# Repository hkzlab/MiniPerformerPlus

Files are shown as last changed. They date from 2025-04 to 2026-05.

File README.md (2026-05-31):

# MiniPerformer+

## DISCLAIMER

Any use of this project is **under your own responsibility**.
You will be responsible of checking the correct construction and functionality of your board.
By using this project You will agree that I cannot be held responsible if it will destroy any of your devices, damage your computer, burn down your house or whatever.

## Introduction

This board is a remix of the [Micromac Performer](https://github.com/TheRealBolle/Performer-SE-PL-CL) reversed by Bolle,
resized for installation on the Macintosh Plus clone I am using.

Ideally, it should be usable on original Mac Pluses too, try and let me know!

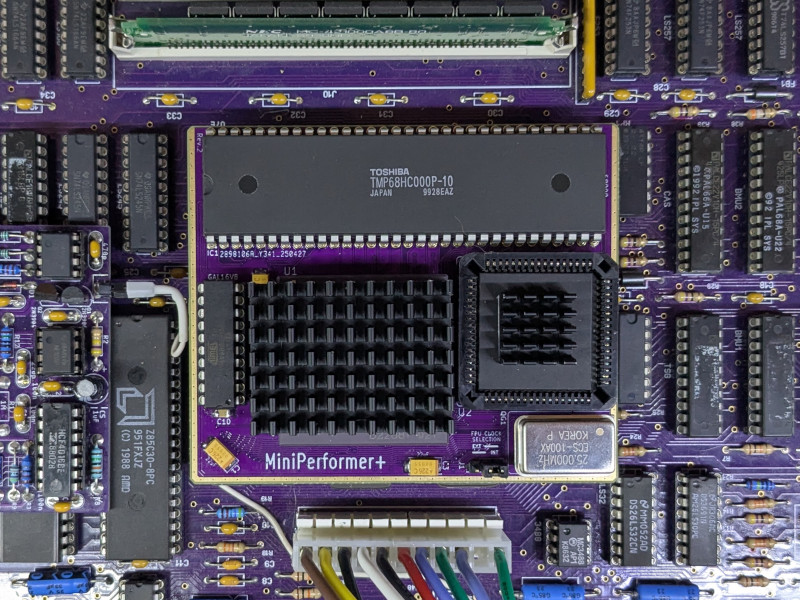
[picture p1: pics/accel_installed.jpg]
Rev. 2 board installed in a Mac Plus clone motherboard


### Caveat Emptor

The original Performer had a clip mounted on the underside that allowed it to snap on the motherboard's 68000 without desoldering.
Those clips are now hard to come by, so this accelerator is meant to be installed in place of the 68000, which has to be desoldered and socketed.

### Ordering the boards

You can order the board for this project at [PCBWay](https://www.pcbway.com/project/shareproject/MiniPerformer_d2c49c46.html) and support me or download 
the gerbers and have them printed wherever you like!!!

## Features

- Relatively easy to build, with socketed PLCC ICs
- ~16Mhz 68030 + optional 68882 with choice of clock source: 16Mhz internal or external oscillator

## Hardware

The board was designed with [KiCad](https://kicad.org/) EDA.

### Bill of Materials

| Component | Qty | Type / Value | Notes |
| --- | --- | --- | --- |
| R1 - R18 |  18 | 4.7k resistors, 1206 | |
| C4 - C14 |  11 | 100nF/16V ceramic cap, 1206 | |
| C1 - C3 |  3  | 22uF/16V or 25V tantalum capacitor, 6032 | |
| 68000 socket |  64 | Female machined pins, >=9.7mm length | You can source these on AliExpress, here is an [example](https://it.aliexpress.com/item/33019740866.html). |
| QG1 |  1  | DIP8 or DIP14 oscillator | Depending on the 68882, I had luck with frequencies ranging between 25 and 50Mhz |
| U1 |  1  | 68030, PGA-128 package | Avoid soldering the CPU to the board, use a socket!!! |
| U2 |  1  | 68882 FPU, optional, PLCC-68 package, requires socket | The FPU is optional, to install it, a PLCC-68 THT socket is required |
| U3 - U6 |  4  | PLCC-20 PLDs, 16V8 compatbile, an SMD PLCC socket is required  | I tested both GAL16V8D and AMD PALCE16V8 PLDs for this |
| U7 |  1  | DIP-20 PLD, 16V8 compatible | Avoid GAL16V8D, tested ATF16V8 and PALCE16V8 without issues |
| J3 |  1  | 3 pin 2.54mm header strip | Used to switch between internal and external clock source for FPU |

### Assembly

Start with the smallest SMD components: ceramic caps and resistors, on both sides of the board.
I usually do the 3 tantalum caps right after, then flip the board and install the 4 PLCC-20 sockets.

For the sockets, my usual approach is to snip away the bottom, apply copious flux on the PCB, align the sockets and then
apply solder, no need for hot air here. You do you though.

The nastiest part is installing the round pins in the 68000 footprint. Insert the pins from the topside of the board, then use a large flat blade screwdriver,
pushing the pins through the hole wiggling the pin completely in. Try not to hurt your fingers (like I did...) in the process.

The installed pins should look like this. Mind you, you will need pins >=9.7mm in length!

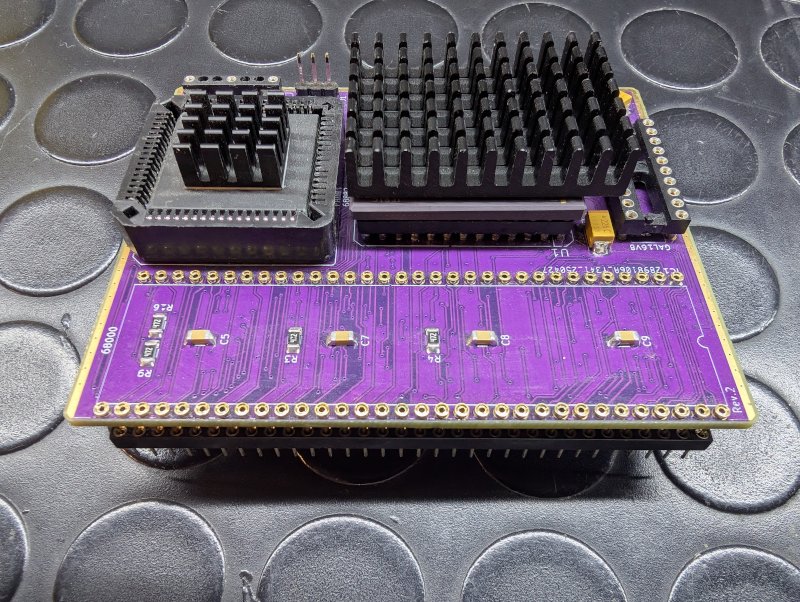
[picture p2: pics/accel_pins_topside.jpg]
Rev. 2 topside view


Once the rows are installed, I usually install a temporary socket on the pins to keep them in line, apply flux on the pcb, then solder every pin on the underside.
Try not to short them.

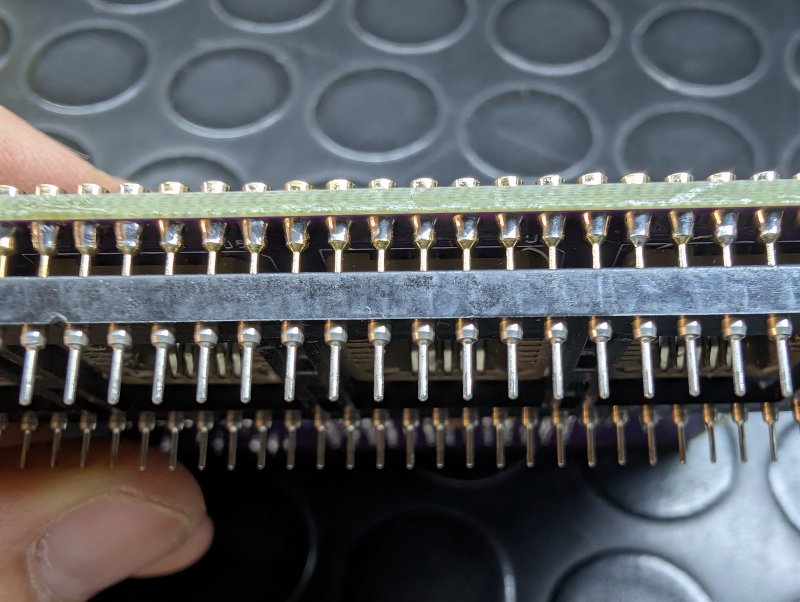
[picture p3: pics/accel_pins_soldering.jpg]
Rev. 2 sideways pins view


You can keep the through hole sockets and the 3 pin header last.

Once the all pins have been soldered, you can **VERY CAREFULLY** remove the holding socket. If you choose long enough pins, the accelerator will have enough clearance
at the bottom to install in the 68000 socket on the motherboard.

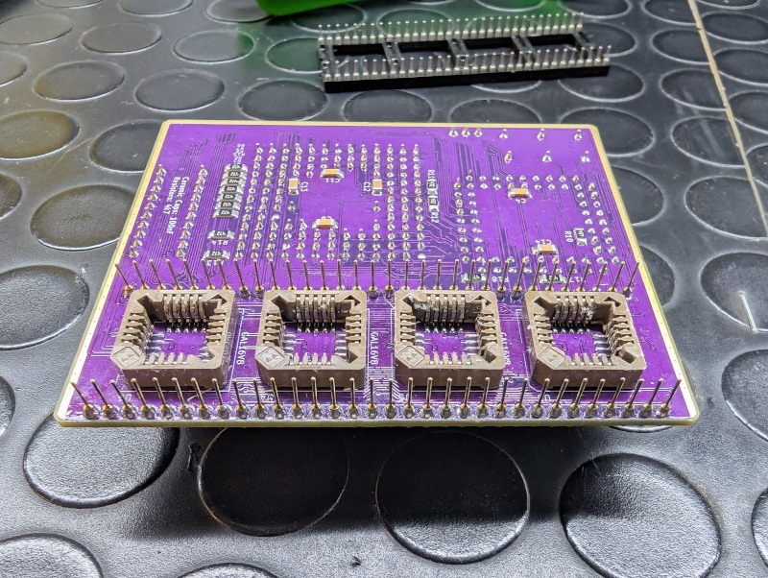
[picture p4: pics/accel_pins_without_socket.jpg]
Rev. 2 bottomside without socket


The PLDs must be programmed, the JED files can be found in [Bolle's repository](https://github.com/TheRealBolle/Performer-SE-PL-CL).

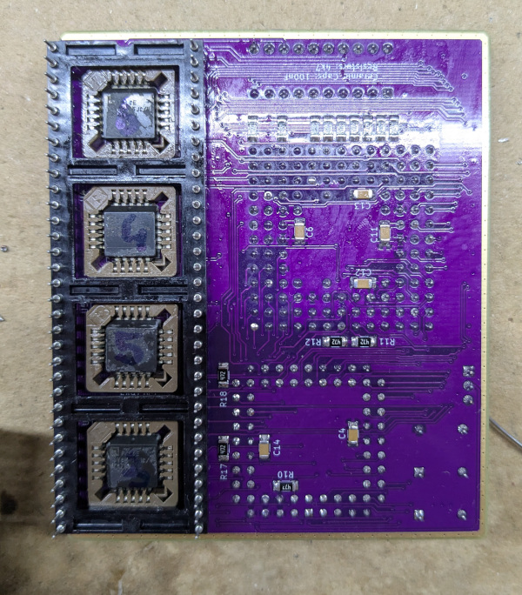
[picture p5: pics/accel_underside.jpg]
Rev. 2 board underside


### How to disable the accelerator

Turn on the Macintosh Plus then, after the chime sound, hold the interrupt button, and push reset after that. After another chime sound plays, release the interrupt button.

The accelerator will be disabled until the next boot.

### Known Issues

- While used without this board, my clone Mac Plus had no issues in using a WDC 65C22 and fast OTP ROMs. With the accelerator installed, it gets a bit finicky on the parts and sometimes refuses to boot at all with those installed. Replacing the ROMs with standard 27C512 rated at around 150nS, plus using a plain old 6522 solved all the boot issues for me. No changes should be necessary on a stock Mac Plus, but let me know how it goes for you.
- Also, note that the choice of PLD type for the build is important, especially for U7: I had good luck with PALCE16V8 rated at 25ns or ATF16V8 rated at 15. Pain and tears with GAL16V8D though.
- Like the original Performer, using this accelerator could get You audio distorsion in some software

### Future Improvements

- Possibly replace U7 with a PLL for configurable speed
- A revision with a QFP 68030?

### Extra

A nice [video](https://www.youtube.com/watch?v=oIT5QKRQgww) by BigBadBiologist on how to abuse a Macintosh Classic with this board meant for a Macintosh Plus!

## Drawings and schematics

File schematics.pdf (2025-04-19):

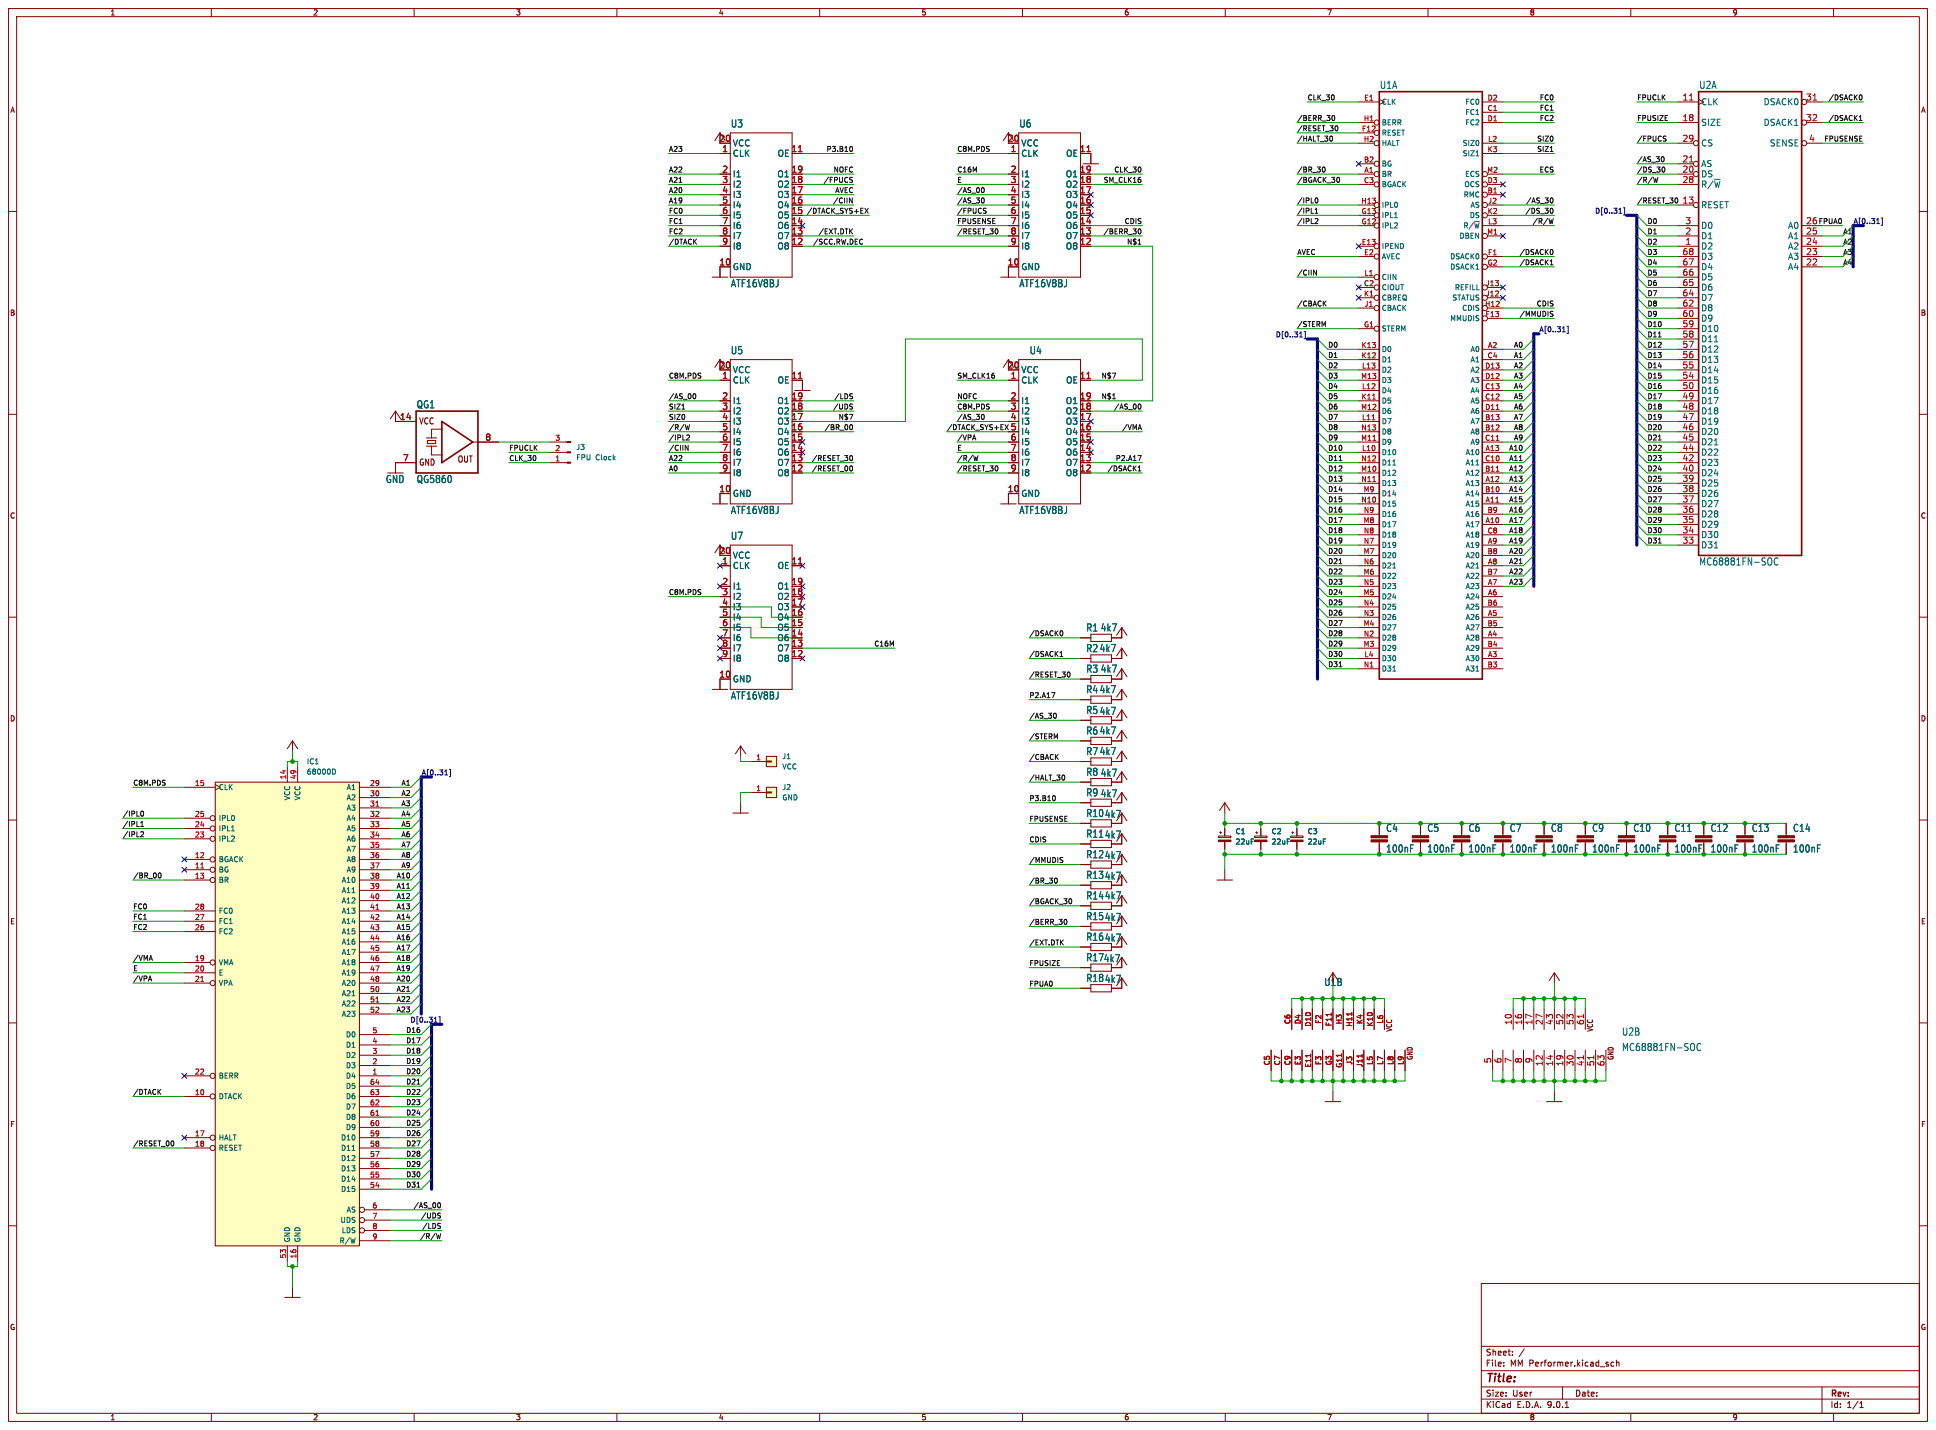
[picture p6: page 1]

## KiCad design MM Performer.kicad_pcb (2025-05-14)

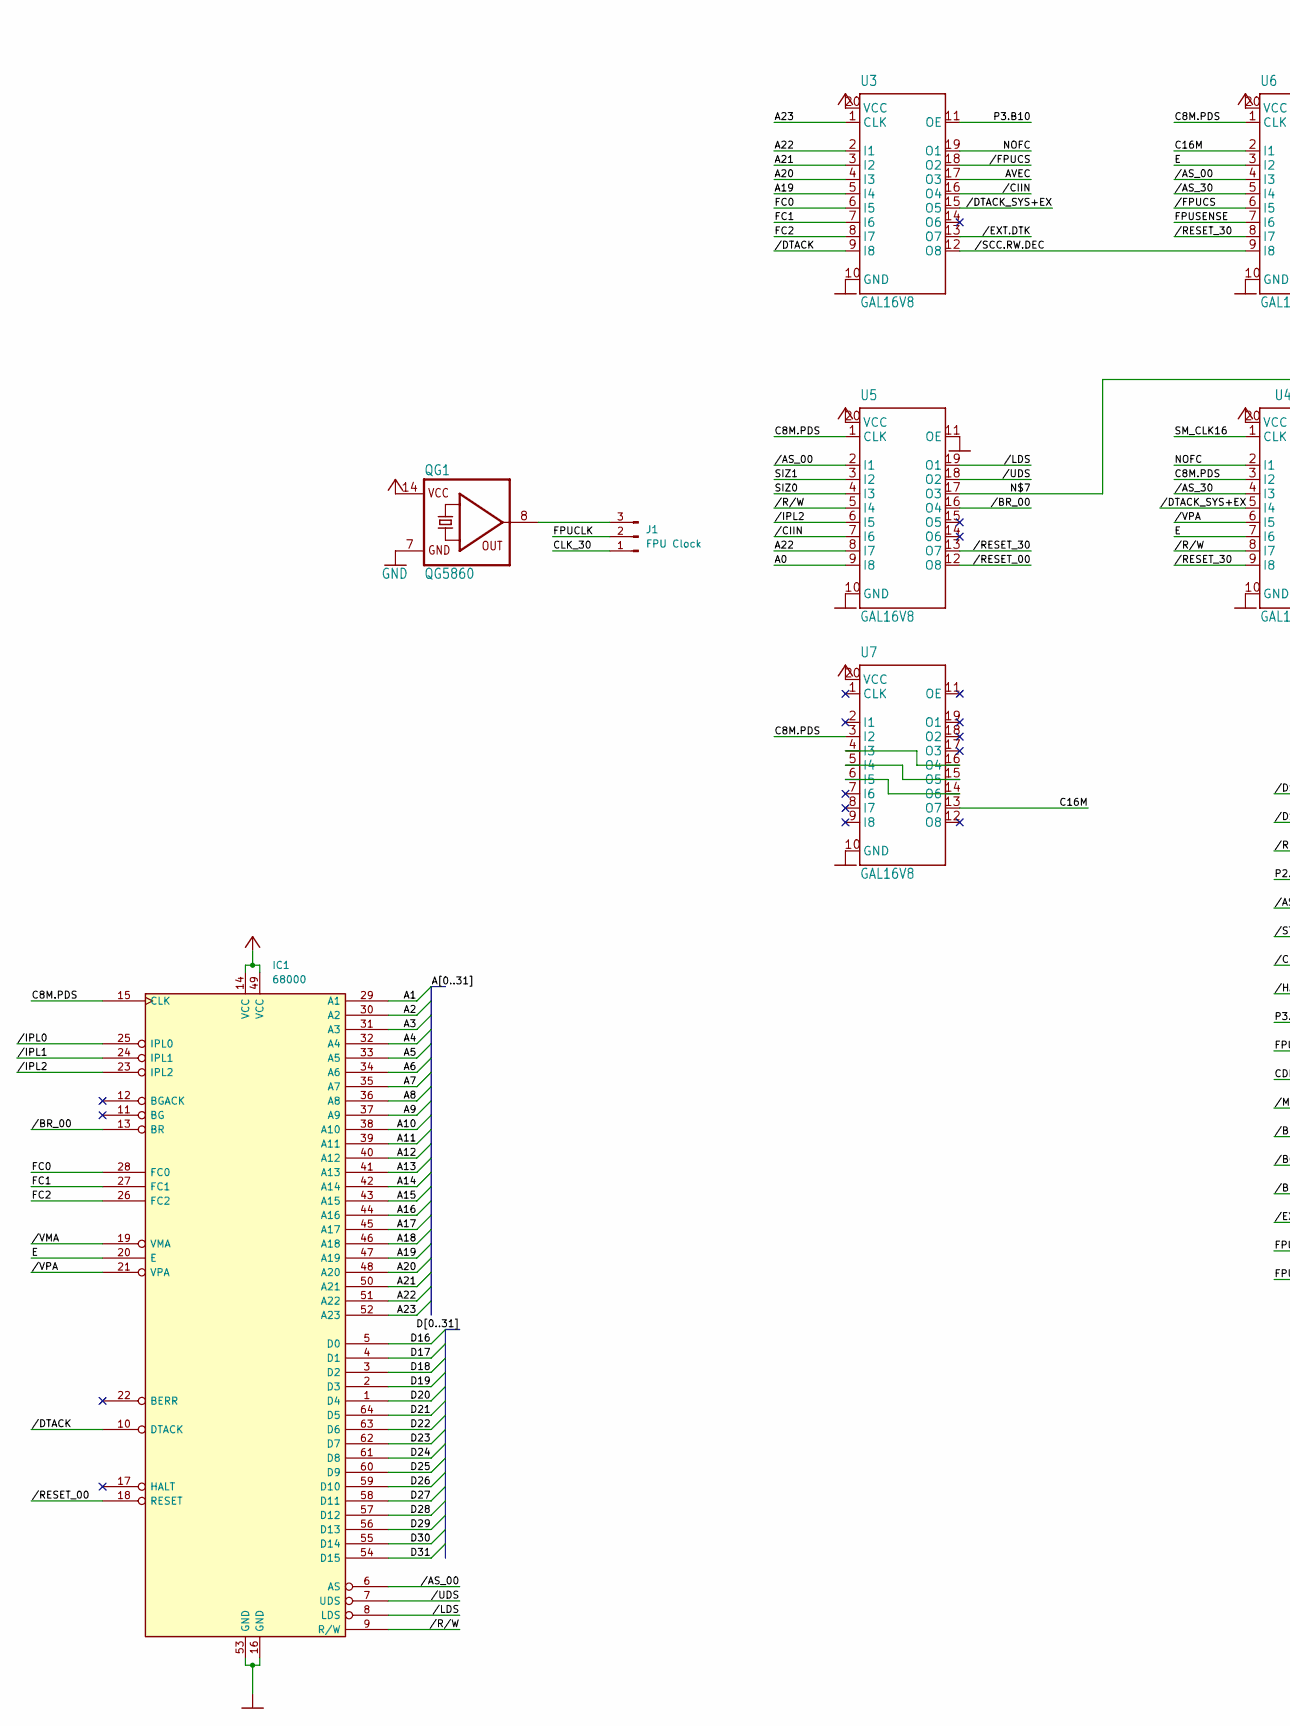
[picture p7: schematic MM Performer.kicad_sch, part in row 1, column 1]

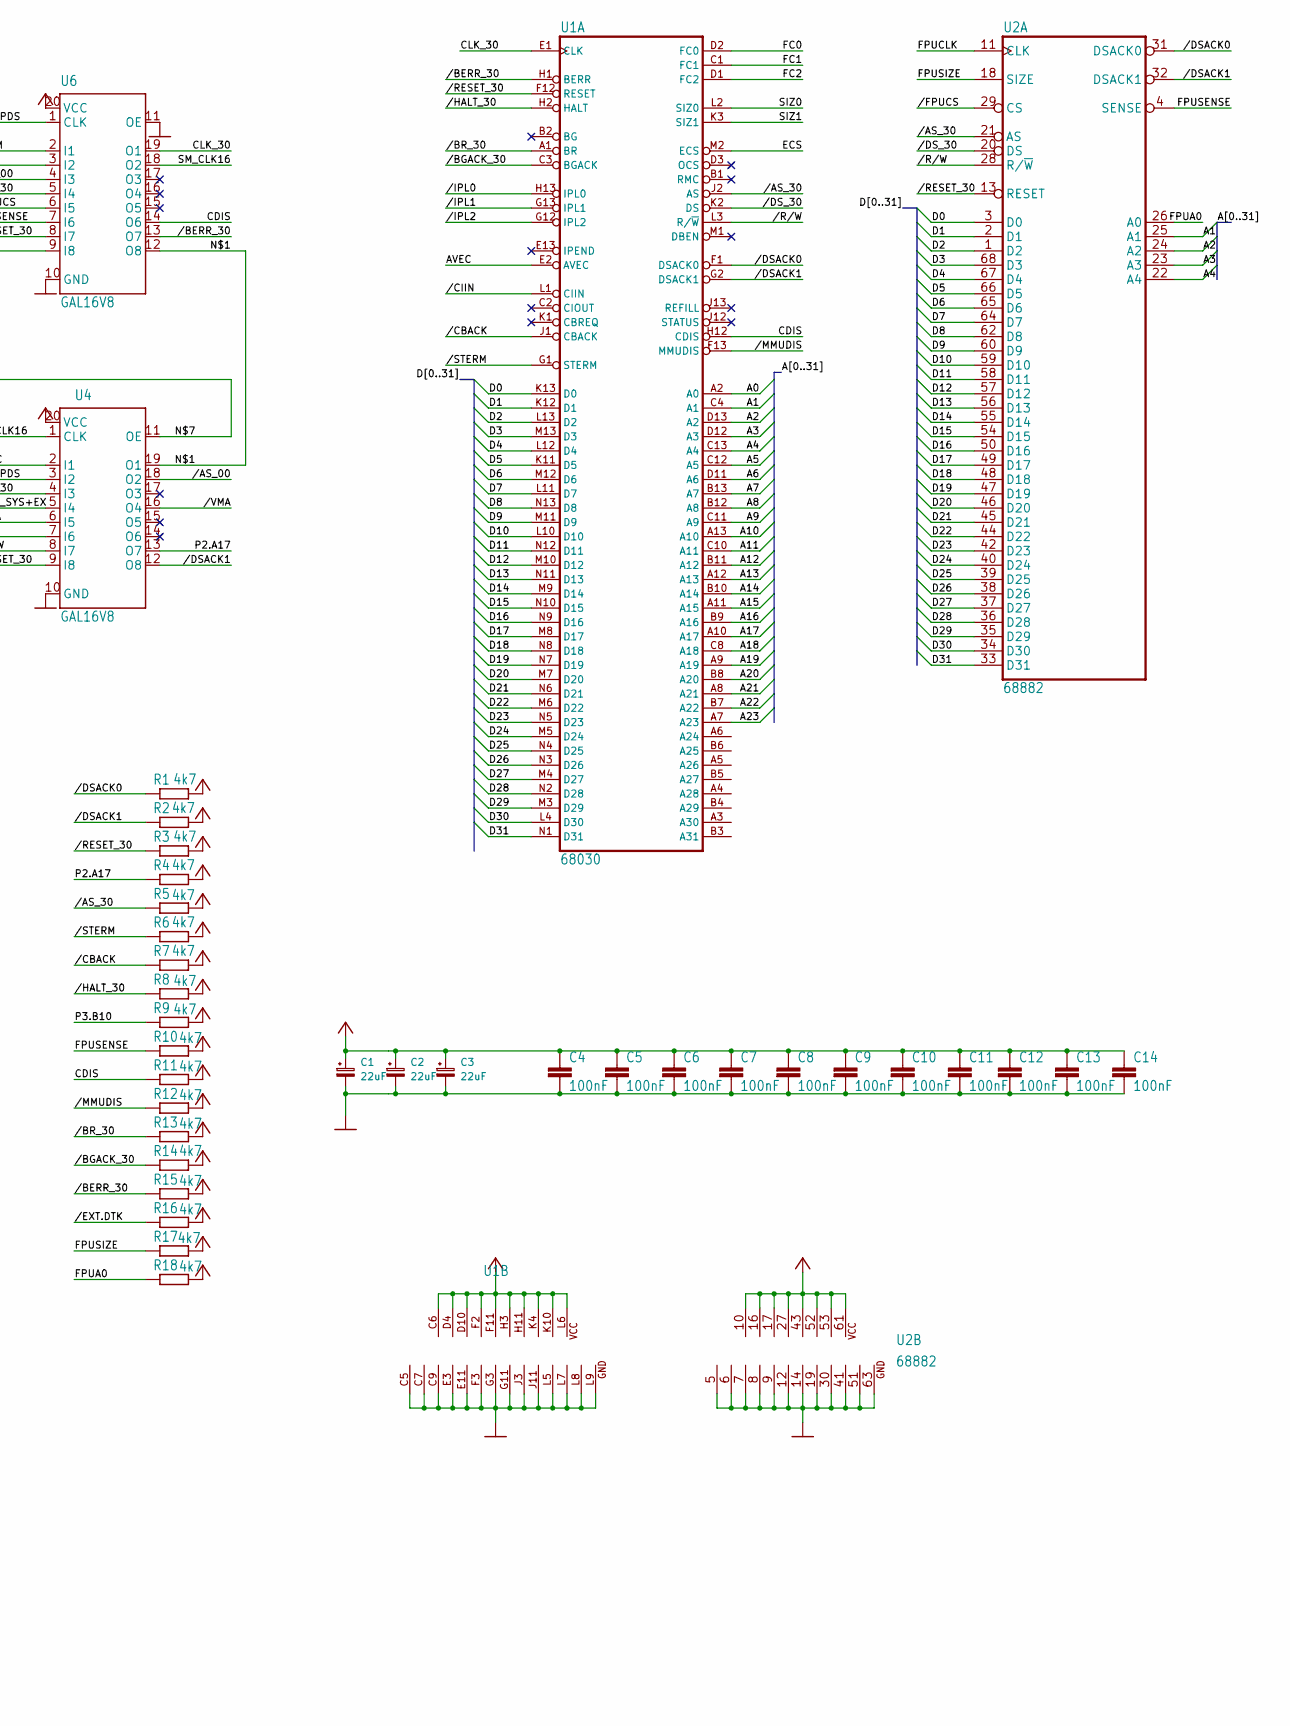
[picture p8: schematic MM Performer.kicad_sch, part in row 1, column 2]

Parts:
C1, C2, C3: 22uF; CP_EIA-6032-28_Kemet-C_Pad2.25x2.35mm_HandSolder
C4, C5, C6, C7, C8, C9, C10, C11, C12, C13, C14: 100nF; C_1206_3216Metric_Pad1.33x1.80mm_HandSolder
IC1: 68000; DIP-64_W22.86mm
J1: FPU Clock; PinHeader_1x03_P2.54mm_Vertical
QG1: QG5860; Oscillator_DIP-14-8
R1, R2, R3, R4, R5, R6, R7, R8, R9, R10, R11, R12, R13, R14, R15, R16, R17, R18: 4k7; R_1206_3216Metric_Pad1.30x1.75mm_HandSolder
U1: 68030; CPGA-128_Layout13x13_MC68030
U2: 68882; PLCC-68_THT-Socket
U3, U4, U5, U6: GAL16V8; PLCC-20_SMD-Socket
U7: GAL16V8; DIP-20_W7.62mm

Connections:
/A0: U1.A2 (A0), U5.9 (I8)
/A1: IC1.29 (A1), U1.C4 (A1), U2.25 (A1)
/A2: IC1.30 (A2), U1.D13 (A2), U2.24 (A2)
/A3: IC1.31 (A3), U1.D12 (A3), U2.23 (A3)
/A4: IC1.32 (A4), U1.C13 (A4), U2.22 (A4)
/A5: IC1.33 (A5), U1.C12 (A5)
/A6: IC1.34 (A6), U1.D11 (A6)
/A7: IC1.35 (A7), U1.B13 (A7)
/A8: IC1.36 (A8), U1.B12 (A8)
/A9: IC1.37 (A9), U1.C11 (A9)
/A10: IC1.38 (A10), U1.A13 (A10)
/A11: IC1.39 (A11), U1.C10 (A11)
/A12: IC1.40 (A12), U1.B11 (A12)
/A13: IC1.41 (A13), U1.A12 (A13)
/A14: IC1.42 (A14), U1.B10 (A14)
/A15: IC1.43 (A15), U1.A11 (A15)
/A16: IC1.44 (A16), U1.B9 (A16)
/A17: IC1.45 (A17), U1.A10 (A17)
/A18: IC1.46 (A18), U1.C8 (A18)
/A19: IC1.47 (A19), U1.A9 (A19), U3.5 (I4)
/A20: IC1.48 (A20), U1.B8 (A20), U3.4 (I3)
/A21: IC1.50 (A21), U1.A8 (A21), U3.3 (I2)
/A22: IC1.51 (A22), U1.B7 (A22), U3.2 (I1), U5.8 (I7)
/A23: IC1.52 (A23), U1.A7 (A23), U3.1 (CLK)
/AVEC: U1.E2 (AVEC), U3.17 (O3)
/C8M.PDS: IC1.15 (CLK), U4.3 (I2), U5.1 (CLK), U6.1 (CLK), U7.3 (I2)
/C16M: U6.2 (I1), U7.13 (O7)
/CDIS: R11.1, U1.H12 (CDIS), U6.14 (O6)
/CLK_30: J1.1, U1.E1 (CLK), U6.19 (O1)
/D0: U1.K13 (D0), U2.3 (D0)
/D1: U1.K12 (D1), U2.2 (D1)
/D2: U1.L13 (D2), U2.1 (D2)
/D3: U1.M13 (D3), U2.68 (D3)
/D4: U1.L12 (D4), U2.67 (D4)
/D5: U1.K11 (D5), U2.66 (D5)
/D6: U1.M12 (D6), U2.65 (D6)
/D7: U1.L11 (D7), U2.64 (D7)
/D8: U1.N13 (D8), U2.62 (D8)
/D9: U1.M11 (D9), U2.60 (D9)
/D10: U1.L10 (D10), U2.59 (D10)
/D11: U1.N12 (D11), U2.58 (D11)
/D12: U1.M10 (D12), U2.57 (D12)
/D13: U1.N11 (D13), U2.56 (D13)
/D14: U1.M9 (D14), U2.55 (D14)
/D15: U1.N10 (D15), U2.54 (D15)
/D16: IC1.5 (D0), U1.N9 (D16), U2.50 (D16)
/D17: IC1.4 (D1), U1.M8 (D17), U2.49 (D17)
/D18: IC1.3 (D2), U1.N8 (D18), U2.48 (D18)
/D19: IC1.2 (D3), U1.N7 (D19), U2.47 (D19)
/D20: IC1.1 (D4), U1.M7 (D20), U2.46 (D20)
/D21: IC1.64 (D5), U1.N6 (D21), U2.45 (D21)
/D22: IC1.63 (D6), U1.M6 (D22), U2.44 (D22)
/D23: IC1.62 (D7), U1.N5 (D23), U2.42 (D23)
/D24: IC1.61 (D8), U1.M5 (D24), U2.40 (D24)
/D25: IC1.60 (D9), U1.N4 (D25), U2.39 (D25)
/D26: IC1.59 (D10), U1.N3 (D26), U2.38 (D26)
/D27: IC1.58 (D11), U1.M4 (D27), U2.37 (D27)
/D28: IC1.57 (D12), U1.N2 (D28), U2.36 (D28)
/D29: IC1.56 (D13), U1.M3 (D29), U2.35 (D29)
/D30: IC1.55 (D14), U1.L4 (D30), U2.34 (D30)
/D31: IC1.54 (D15), U1.N1 (D31), U2.33 (D31)
/E: IC1.20 (E), U4.7 (I6), U6.3 (I2)
/ECS: U1.M2 (ECS)
/FC0: IC1.28 (FC0), U1.D2 (FC0), U3.6 (I5)
/FC1: IC1.27 (FC1), U1.C1 (FC1), U3.7 (I6)
/FC2: IC1.26 (FC2), U1.D1 (FC2), U3.8 (I7)
/FPUA0: R18.1, U2.26 (A0)
/FPUCLK: J1.2, U2.11 (CLK)
/FPUSENSE: R10.1, U2.4 (SENSE), U6.7 (I6)
/FPUSIZE: R17.1, U2.18 (SIZE)
/N$1: U4.19 (O1), U6.12 (O8)
/N$7: U4.11 (OE), U5.17 (O3)
/NOFC: U3.19 (O1), U4.2 (I1)
/P2.A17: R4.1, U4.13 (O7)
/P3.B10: R9.1, U3.11 (OE)
/SIZ0: U1.L2 (SIZ0), U5.4 (I3)
/SIZ1: U1.K3 (SIZ1), U5.3 (I2)
/SM_CLK16: U4.1 (CLK), U6.18 (O2)
//AS_00: IC1.6 (AS), U4.18 (O2), U5.2 (I1), U6.4 (I3)
//AS_30: R5.1, U1.J2 (AS), U2.21 (AS), U4.4 (I3), U6.5 (I4)
//BERR_30: R15.1, U1.H1 (BERR), U6.13 (O7)
//BGACK_30: R14.1, U1.C3 (BGACK)
//BR_00: IC1.13 (BR), U5.16 (O4)
//BR_30: R13.1, U1.A1 (BR)
//CBACK: R7.1, U1.J1 (CBACK)
//CIIN: U1.L1 (CIIN), U3.16 (O4), U5.7 (I6)
//DSACK0: R1.1, U1.F1 (DSACK0), U2.31 (DSACK0)
//DSACK1: R2.1, U1.G2 (DSACK1), U2.32 (DSACK1), U4.12 (O8)
//DS_30: U1.K2 (DS), U2.20 (DS)
//DTACK: IC1.10 (DTACK), U3.9 (I8)
//DTACK_SYS+EX: U3.15 (O5), U4.5 (I4)
//EXT.DTK: R16.1, U3.13 (O7)
//FPUCS: U2.29 (CS), U3.18 (O2), U6.6 (I5)
//HALT_30: R8.1, U1.H2 (HALT)
//IPL0: IC1.25 (IPL0), U1.H13 (IPL0)
//IPL1: IC1.24 (IPL1), U1.G13 (IPL1)
//IPL2: IC1.23 (IPL2), U1.G12 (IPL2), U5.6 (I5)
//LDS: IC1.8 (LDS), U5.19 (O1)
//MMUDIS: R12.1, U1.F13 (MMUDIS)
//RESET_00: IC1.18 (RESET), U5.12 (O8)
//RESET_30: R3.1, U1.F12 (RESET), U2.13 (RESET), U4.9 (I8), U5.13 (O7), U6.8 (I7)
//R/W: IC1.9 (R/W), U1.L3 (R/~W), U2.28 (R/~W), U4.8 (I7), U5.5 (I4)
//SCC.RW.DEC: U3.12 (O8), U6.9 (I8)
//STERM: R6.1, U1.G1 (STERM)
//UDS: IC1.7 (UDS), U5.18 (O2)
//VMA: IC1.19 (VMA), U4.16 (O4)
//VPA: IC1.21 (VPA), U4.6 (I5)
GND: C1.2, C2.2, C3.2, C4.2, C5.2, C6.2, C7.2, C8.2, C9.2, C10.2, C11.2, C12.2, C13.2, C14.2, IC1.16 (GND), IC1.53 (GND), QG1.7 (GND), U1.C5 (GND@1), U1.C7 (GND@2), U1.C9 (GND@3), U1.E3 (GND@4), U1.E11 (GND@5), U1.F3 (GND@6), U1.G3 (GND@7), U1.G11 (GND@8), U1.J3 (GND@9), U1.J11 (GND@10), U1.L5 (GND@11), U1.L7 (GND@12), U1.L8 (GND@13), U1.L9 (GND@14), U2.5 (GND@1), U2.6 (GND@2), U2.7 (GND@3), U2.8 (GND@4), U2.9 (GND@5), U2.12 (GND@6), U2.14 (GND@7), U2.19 (GND@8), U2.30 (GND@9), U2.41 (GND@10), U2.51 (GND@11), U2.63 (GND@12), U3.10 (GND), U4.10 (GND), U5.10 (GND), U5.11 (OE), U6.10 (GND), U6.11 (OE), U7.10 (GND)
unnamed: J1.3, QG1.8 (OUT)
unnamed: U7.4 (I3), U7.16 (O4)
unnamed: U7.5 (I4), U7.15 (O5)
unnamed: U7.6 (I5), U7.14 (O6)
VCC: C1.1, C2.1, C3.1, C4.1, C5.1, C6.1, C7.1, C8.1, C9.1, C10.1, C11.1, C12.1, C13.1, C14.1, IC1.14 (VCC), IC1.49 (VCC), QG1.14 (VCC), R1.2, R2.2, R3.2, R4.2, R5.2, R6.2, R7.2, R8.2, R9.2, R10.2, R11.2, R12.2, R13.2, R14.2, R15.2, R16.2, R17.2, R18.2, U1.C6 (VCC@1), U1.D4 (VCC@2), U1.D10 (VCC@3), U1.F2 (VCC@4), U1.F11 (VCC@5), U1.H3 (VCC@6), U1.H11 (VCC@7), U1.K4 (VCC@8), U1.K10 (VCC@9), U1.L6 (VCC@10), U2.10 (VCC@1), U2.16 (VCC@2), U2.17 (VCC@3), U2.27 (VCC@4), U2.43 (VCC@5), U2.52 (VCC@6), U2.53 (VCC@7), U2.61 (VCC@8), U3.20 (VCC), U4.20 (VCC), U5.20 (VCC), U6.20 (VCC), U7.20 (VCC)

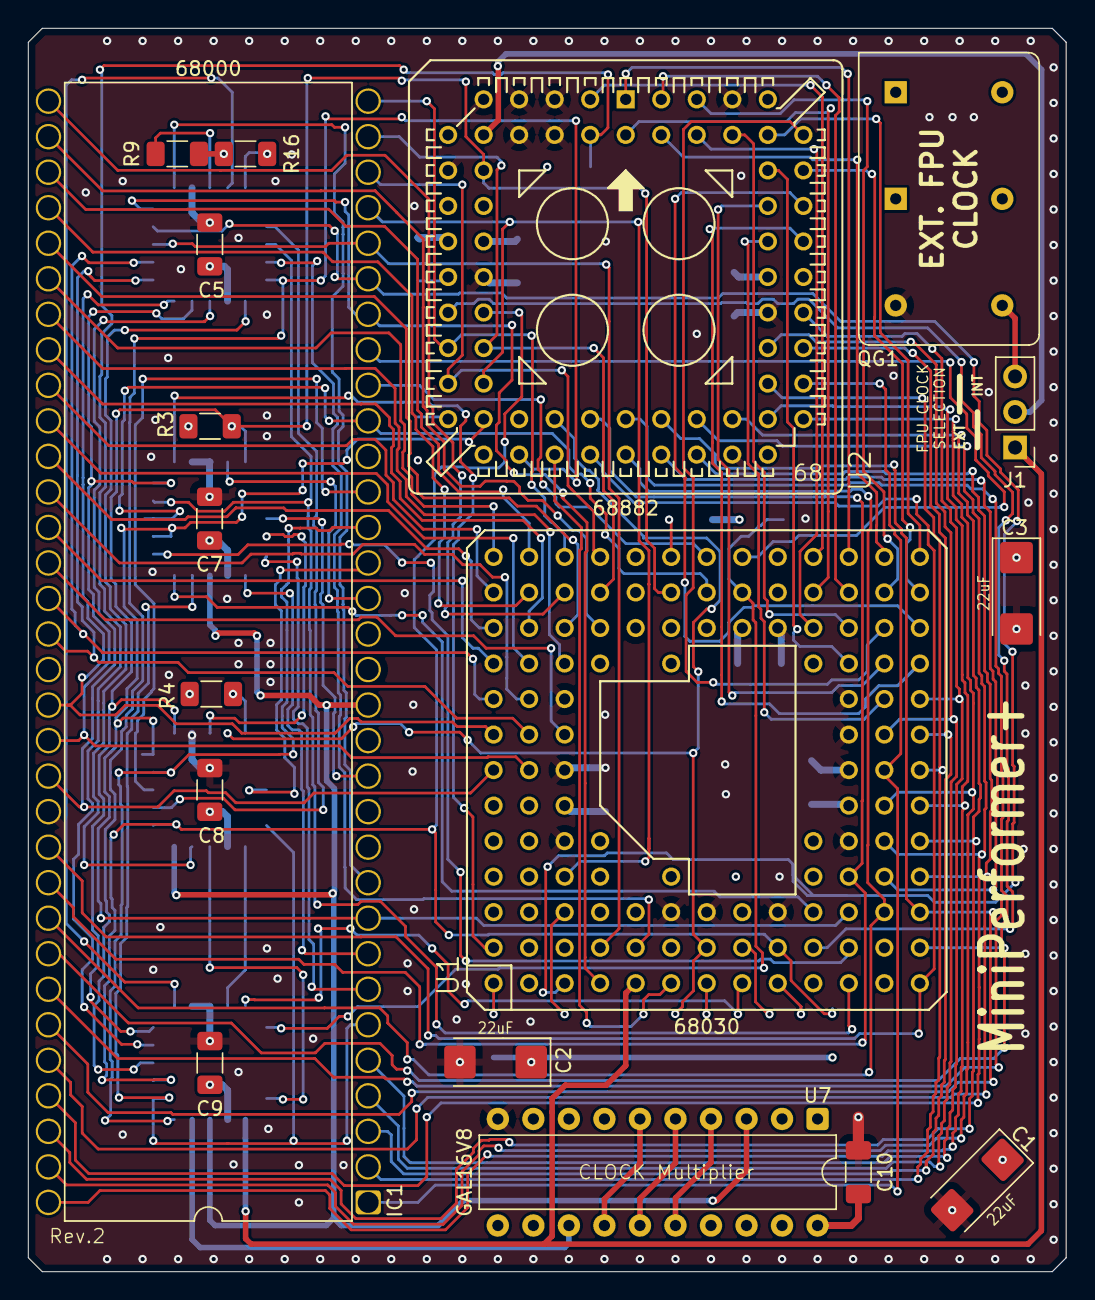
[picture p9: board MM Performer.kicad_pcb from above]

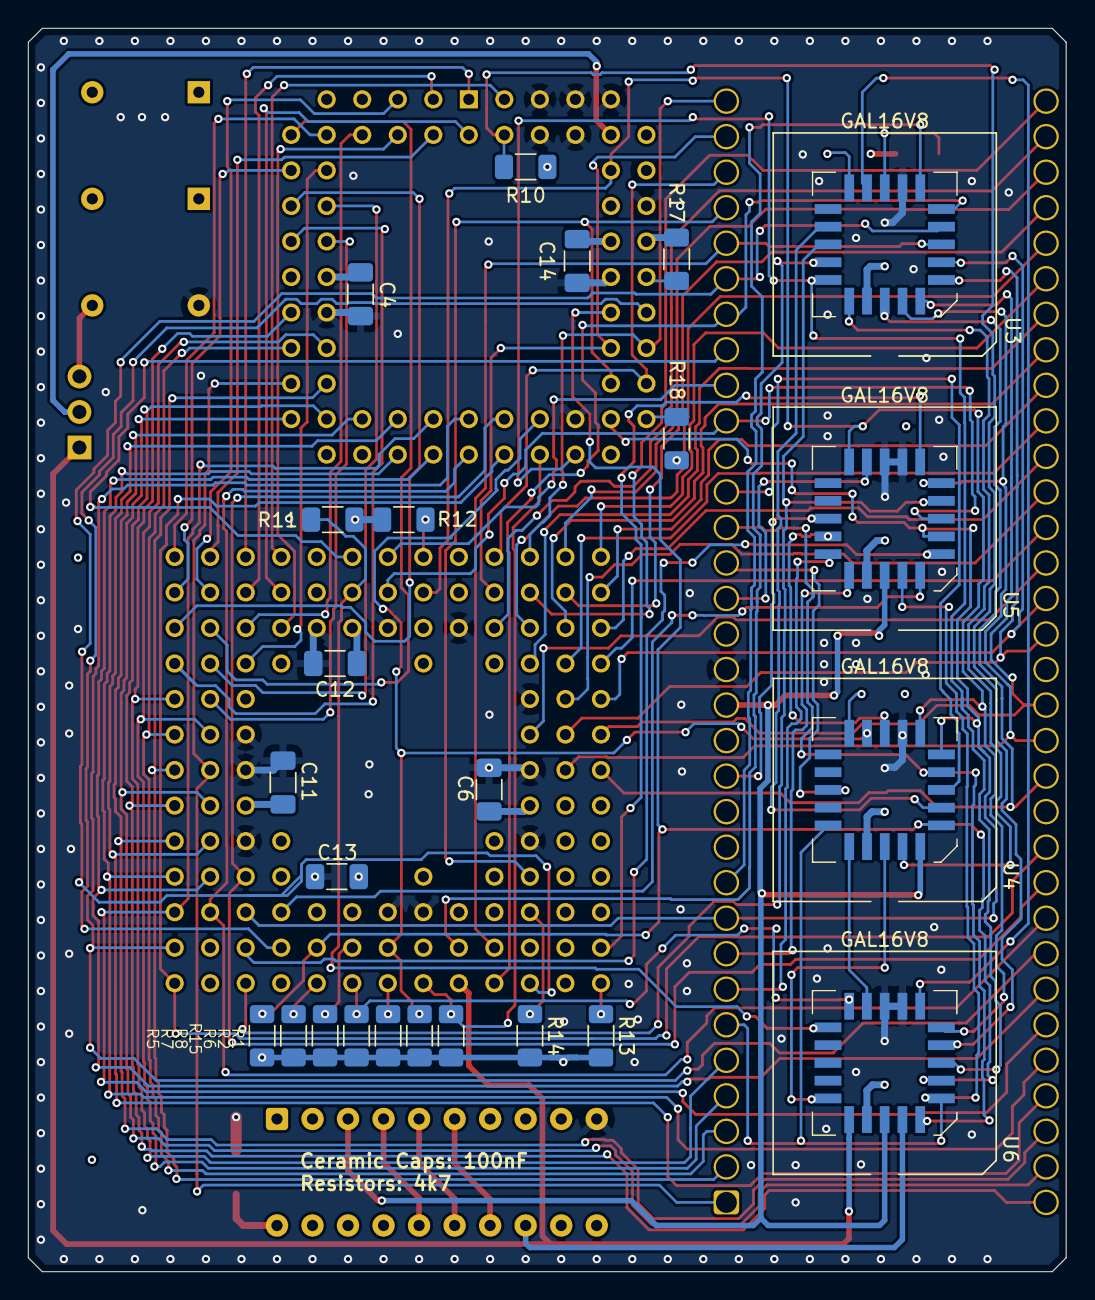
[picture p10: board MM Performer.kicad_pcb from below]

Board: 4 copper layers, 74.2 x 88.9 mm, 42 parts (24 on the bottom side), 112 nets.

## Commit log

2025-03-03 First import
    [MM Performer.kicad_pcb, MM Performer.kicad_sch]
2025-03-03 Tweak positioning a bit
    [MM Performer.kicad_pcb, MM Performer.kicad_sch]
2025-03-03 Reorganize a bit
    [MM Performer.kicad_pcb, MM Performer.kicad_sch]
2025-03-03 Reorganize the positions
    [MM Performer.kicad_pcb, MM Performer.kicad_sch]
2025-03-03 Current setup
    [MM Performer.kicad_pcb]
2025-03-03 Update footprints
    [MM Performer.kicad_pcb]
2025-03-03 Draw PCB
    [MM Performer.kicad_pcb, MM Performer.kicad_sch]
2025-03-28 Change width of a VCC trace
    [MM Performer.kicad_pcb]
2025-03-29 Cleaning up the schematic
    [MM Performer.kicad_sch]
2025-03-29 Further cleanup
    [MM Performer.kicad_sch]
2025-03-31 Begin cleanup of the traces for the new revision
    [MM Performer.kicad_pcb, MM Performer.kicad_sch]
2025-03-31 Reorganize placement on the PCB
    [MM Performer.kicad_pcb, MM Performer.kicad_sch]
2025-03-31 Reorganize the board again
    [MM Performer.kicad_pcb]
2025-03-31 Initial routing of clock and power traces
    [MM Performer.kicad_pcb]
2025-04-01 Some rerouting of traces
    [MM Performer.kicad_pcb, MM Performer.kicad_sch]
2025-04-01 Update routing
    [MM Performer.kicad_pcb]
2025-04-01 Move cap near CPU
    [MM Performer.kicad_pcb]
2025-04-01 Tweak the routing some more
    [MM Performer.kicad_pcb]
2025-04-01 Further signal tweaks
    [MM Performer.kicad_pcb]
2025-04-01 Further tweaks
    [MM Performer.kicad_pcb]
2025-04-01 Tweak placement again
    [MM Performer.kicad_pcb]
2025-04-01 Reposition CPU
    [MM Performer.kicad_pcb]
2025-04-02 Route traces, add zones
    [MM Performer.kicad_pcb]
2025-04-02 Further silkscreen changes and trace rerouting
    [MM Performer.kicad_pcb]
2025-04-02 Begin fixing the autorouter's mess
    [MM Performer.kicad_pcb]
2025-04-02 Further tweaks to routing
    [MM Performer.kicad_pcb]
2025-04-02 Further fixes to traces
    [MM Performer.kicad_pcb]
2025-04-02 Add silkscreen for caps/resistor values
    [MM Performer.kicad_pcb]
2025-04-05 Generate gerbers for rev_1
    [MM Performer.kicad_pcb]
2025-04-17 Moved around two resistor markings
    [MM Performer.kicad_pcb]
2025-04-19 Add schematics, regenerate gerber
    [MM Performer.kicad_pcb]
2025-04-19 Remove section on board ordering
2025-04-19 Mention PCBWay for ordering boards
2025-05-14 Import revision 2 board
    [MM Performer.kicad_pcb, MM Performer.kicad_sch]
